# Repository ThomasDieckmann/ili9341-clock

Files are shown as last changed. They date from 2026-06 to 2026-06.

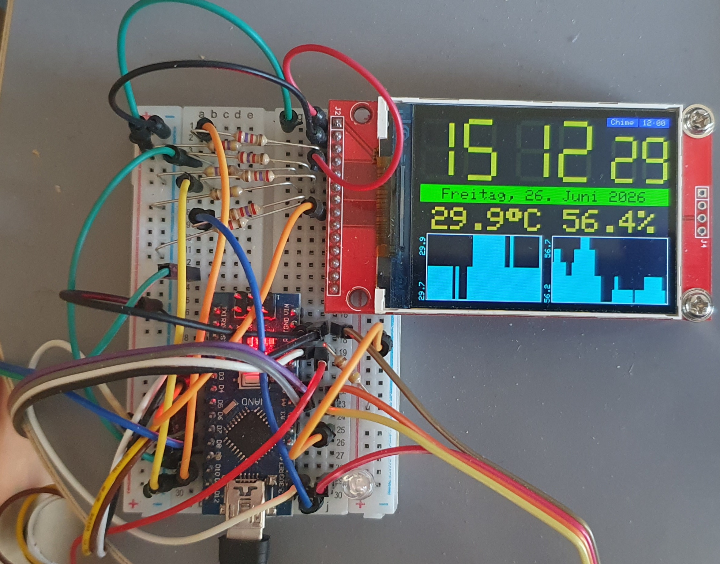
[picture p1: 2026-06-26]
pictures/20260626_144947.jpg

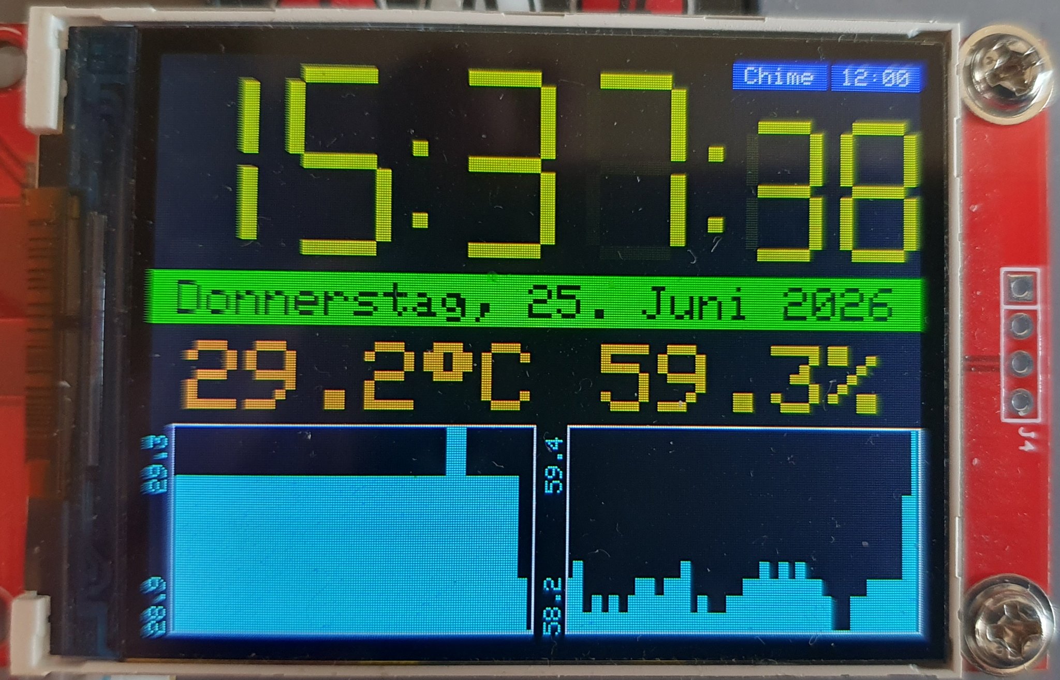
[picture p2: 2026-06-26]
pictures/ili9341-clock.jpeg

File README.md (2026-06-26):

# Uhr mit ILI9341 display

Das war eigentlich eine schnelle Bastelei, die auch zugegebenermaßen noch nicht ganz fertig ist.
So sieht der Code allerdings auch aus. Da könnten irgendwann noch einmal ein paar Kommentare hinein.

Hinweise:
- Viele dieser LCD-Displays kommen als 3,3V-Version ohne Pegelwandler auf den Markt. Daher habe ich
  im Schaltplan die Spannungsteiler eingesetzt. Sollten Pegelwandler verbaut sein, kann der Spannungsteiler
  entfallen und das Display direkt angeschlossen werden.
- Dass alle Segmente gezeichnet werden, ist gewollt. Die inaktiven Segmente werden in einer dunkleren
  Farbe dargestellt, damit der Eindruck eines 7-Segment LED-Displays entsteht. Wen's stört, der kann
  das im Code gerne auf schwarz stellen.

TODO:
- Integration LDR im Code => Steuern LED Hintergrundbeleuchtung
- Alarmfunktion
- Chime-Funktion
- präziseres RTC-Modul finden

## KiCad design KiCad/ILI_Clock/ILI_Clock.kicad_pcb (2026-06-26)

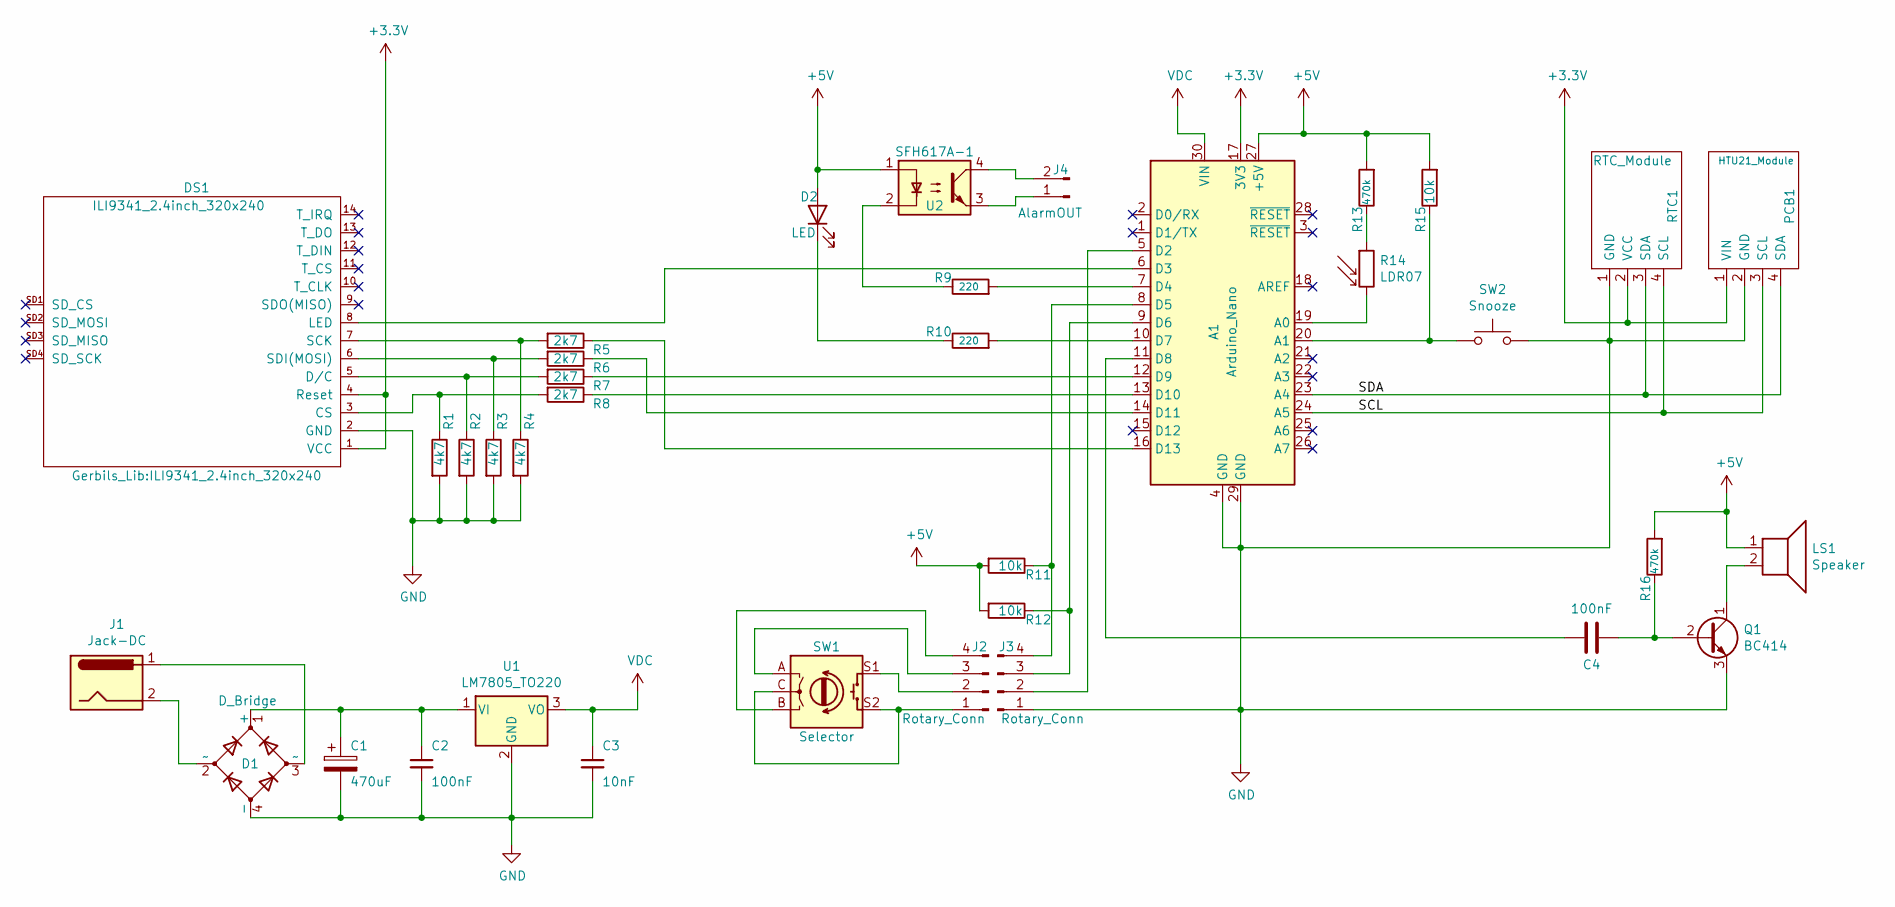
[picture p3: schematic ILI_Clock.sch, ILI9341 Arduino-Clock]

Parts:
A1: Arduino_Nano
C1: 470uF; CP_Radial_D8.0mm_P5.00mm
C2: 100nF; C_Axial_L3.8mm_D2.6mm_P10.00mm_Horizontal
C3: 10nF; C_Axial_L3.8mm_D2.6mm_P10.00mm_Horizontal
C4: 100nF; C_Axial_L5.1mm_D3.1mm_P10.00mm_Horizontal
D1: D_Bridge; Diode_Bridge_Round_D9.8mm
D2: LED; PinHeader_1x02_P2.54mm_Vertical
DS1: ILI9341_2.4inch_320x240
J1: Jack-DC; BarrelJack_CUI_PJ-063AH_Horizontal_CircularHoles
J2, J3: Rotary_Conn; PinHeader_1x04_P2.54mm_Vertical
J4: AlarmOUT; PinHeader_1x02_P2.54mm_Vertical
LS1: Speaker; Buzzer_TDK_PS1240P02BT_D12.2mm_H6.5mm
PCB1: HTU21_Module; HTU21
Q1: BC414; TO-92_Inline
R1, R2, R3, R4: 4k7; R_Axial_DIN0411_L9.9mm_D3.6mm_P12.70mm_Horizontal
R5, R6, R7, R8: 2k7; R_Axial_DIN0411_L9.9mm_D3.6mm_P12.70mm_Horizontal
R9, R10: 220; R_Axial_DIN0411_L9.9mm_D3.6mm_P12.70mm_Horizontal
R11, R12, R15: 10k; R_Axial_DIN0411_L9.9mm_D3.6mm_P12.70mm_Horizontal
R13, R16: 470k; R_Axial_DIN0411_L9.9mm_D3.6mm_P12.70mm_Horizontal
R14: LDR07; R_LDR_5.1x4.3mm_P3.4mm_Vertical
RTC1: RTC_Module; PinHeader_1x04_P2.54mm_Vertical
SW1: Selector; RotaryEncoder_Alps_EC11E-Switch_Vertical_H20mm
SW2: Snooze; PinHeader_1x02_P2.54mm_Vertical
U1: LM7805_TO220; TO-220-3_Horizontal_TabDown
U2: SFH617A-1; DIP-4_W7.62mm

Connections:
+3V3: A1.17 (3V3), DS1.1 (VCC), DS1.4 (Reset), PCB1.1 (VIN), RTC1.2 (VCC)
+5V: A1.27 (+5V), D2.2 (A), LS1.1, R11.2, R12.2, R13.2, R15.2, R16.2, U2.1
/SCL: A1.24 (A5), PCB1.3 (SCL), RTC1.4 (SCL)
/SDA: A1.23 (A4), PCB1.4 (SDA), RTC1.3 (SDA)
GND: A1.4 (GND), A1.29 (GND), C1.2, C2.2, C3.2, D1.4 (-), DS1.2 (GND), J3.1, PCB1.2 (GND), Q1.3 (E), R1.2, R2.2, R3.2, R4.2, RTC1.1 (GND), SW2.2, U1.2 (GND)
unnamed: A1.5 (D2), J3.2
unnamed: A1.6 (D3), DS1.8 (LED)
unnamed: A1.7 (D4), R9.2
unnamed: A1.8 (D5), J3.4, R11.1
unnamed: A1.9 (D6), J3.3, R12.1
unnamed: A1.10 (D7), R10.2
unnamed: A1.11 (D8), C4.2
unnamed: A1.12 (D9), R7.1
unnamed: A1.13 (D10), R8.1
unnamed: A1.14 (D11), R6.1
unnamed: A1.16 (D13), R5.1
unnamed: A1.19 (A0), R14.2
unnamed: A1.20 (A1), R15.1, SW2.1
unnamed: C1.1, C2.1, D1.1 (+), U1.1 (VI)
unnamed: C4.1, Q1.2 (B), R16.1
unnamed: D1.2 (~~), J1.2
unnamed: D1.3 (~~), J1.1
unnamed: D2.1 (K), R10.1
unnamed: DS1.3 (CS), R1.1, R8.2
unnamed: DS1.5 (D/C), R2.1, R7.2
unnamed: DS1.6 (SDI(MOSI)), R3.1, R6.2
unnamed: DS1.7 (SCK), R4.1, R5.2
unnamed: J2.1, SW1.C, SW1.S2
unnamed: J2.2, SW1.S1
unnamed: J2.3, SW1.A
unnamed: J2.4, SW1.B
unnamed: J4.1, U2.3
unnamed: J4.2, U2.4
unnamed: LS1.2, Q1.1 (C)
unnamed: R9.1, U2.2
unnamed: R13.1, R14.1
VDC: A1.30 (VIN), C3.1, U1.3 (VO)

Board: 2 copper layers, 36 parts (0 on the bottom side), 37 nets, no tracks yet.

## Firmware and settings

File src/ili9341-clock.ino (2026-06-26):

// #define DEBUG           // general debugging
// #define DISPLAY_ALIGN   // debug display alignment
// #define SET_TIME        // set time for first run
// #define DEBUG_STATS     // debugging for statistics
// #define DEBUG_DATE      // debugging date display

#include "SPI.h"
#include "Adafruit_GFX.h"
#include "Adafruit_ILI9341.h"

#include <Wire.h>
#include "RTClib.h"
#include "SparkFunHTU21D.h"

/*  define the 7 segments: https://en.wikipedia.org/wiki/Seven-segment_display
         _____
      _ <__A__> _ 
     | |       | |
     | |       | |
     |F|       |B|
     | |       | |
     |_| _____ |_|
      _ <__G__> _ 
     | |       | |
     | |       | |
     |E|       |C|
     | |       | |
     |_| _____ |_|
        <__D__>         */

/* Color definitions
#define ILI9341_BLACK 0x0000       ///<   0,   0,   0
#define ILI9341_NAVY 0x000F        ///<   0,   0, 123
#define ILI9341_DARKGREEN 0x03E0   ///<   0, 125,   0
#define ILI9341_DARKCYAN 0x03EF    ///<   0, 125, 123
#define ILI9341_MAROON 0x7800      ///< 123,   0,   0
#define ILI9341_PURPLE 0x780F      ///< 123,   0, 123
#define ILI9341_OLIVE 0x7BE0       ///< 123, 125,   0
#define ILI9341_LIGHTGREY 0xC618   ///< 198, 195, 198
#define ILI9341_DARKGREY 0x7BEF    ///< 123, 125, 123
#define ILI9341_BLUE 0x001F        ///<   0,   0, 255
#define ILI9341_GREEN 0x07E0       ///<   0, 255,   0
#define ILI9341_CYAN 0x07FF        ///<   0, 255, 255
#define ILI9341_RED 0xF800         ///< 255,   0,   0
#define ILI9341_MAGENTA 0xF81F     ///< 255,   0, 255
#define ILI9341_YELLOW 0xFFE0      ///< 255, 255,   0
#define ILI9341_WHITE 0xFFFF       ///< 255, 255, 255
#define ILI9341_ORANGE 0xFD20      ///< 255, 165,   0
#define ILI9341_GREENYELLOW 0xAFE5 ///< 173, 255,  41
#define ILI9341_PINK 0xFC18        ///< 255, 130, 198   */

// For the Adafruit shield, these are the default.
#define TFT_DC     9
#define TFT_CS    10
#define TFT_MISO  12
#define TFT_MOSI  11
#define TFT_CLK   13
#define TFT_RST   A7

#define BAUDRATE 115200
#define LEDPIN 3

#define CLK_PIN           6    // Rotary Encoder Pins  // Definition der Pins. CLK an D6, DT an D5. 
#define DT_PIN            5    // Rotary Encoder Pins
#define SW_PIN            2    // Switch is connected to D2 Verbunden. CAVE : use an interrupt pin!
#define MAXMENU           8    // Anzahl der Setup-Menü-Einträge
#define MAXVALUES        40    // array sizes for temp and humid stats
//#define MAXVALUES        3    // array sizes for temp and humid stats
#define DEFAULT_BRIGHT   50    // default brightness

int   date_text_length      = 0,
      encoderVal            = 0,
      change                = 0,
      MenuSelection         = MAXMENU,  // default Menü-Eintrag
      date_year             = 2021,
      segment_height        = 20, // 7-Segment-Display values
      segment_width         = 5,
      segment_color         = ILI9341_BLUE,
      humd_array[MAXVALUES],
      temp_array[MAXVALUES],
      array_pointer         = -1,
      maximum_temp          = -32000,
      minimum_temp          = 32000,
      maximum_humd          = 0,
      minimum_humd          = 2000;

bool  SelectCelsius         = true,
      AlarmOnOff            = true,
      HourChime             = true,
      SW_pressed            = false,
      adjust_alarm_hour     = false,
      adjust_alarm_minute   = false,
      adjust_time_hour     = false,
      adjust_time_minute   = false,
      adjust_date_day       = false,
      adjust_date_month     = false,
      adjust_date_year      = false,
      time_has_changed      = false,
      date_has_changed      = false,
      alarm_has_changed     = true,
      chime_has_changed     = true,
      stats_have_changed    = true,
      year_can_be_added     = false,   // append 4-digit year to output string
      locking_insert_stats  = false;   // can lock this, to prevent inserting multiple same values in one second

byte  stunde_digit1_alt     = 11,  // init-Werte egal, Hauptsache Unterscheidlich alt ./. neu
      stunde_digit2_alt     = 11,
      stunde_digit1_neu     = 1,
      stunde_digit2_neu     = 1,
      minute_digit1_alt     = 11,
      minute_digit2_alt     = 11,
      minute_digit1_neu     = 1,
      minute_digit2_neu     = 1,
      sekunde_digit1_alt    = 11,
      sekunde_digit2_alt    = 11,
      sekunde_digit1_neu    = 1,
      sekunde_digit2_neu    = 1,
      alarm_hour            = 12,
      alarm_minute          = 0,
      time_hour             = 12,
      time_minute           = 0,
      date_day              = 1,
      date_day_old          = 32,  // first run, we'll draw a date
      date_month            = 1,
      display_brightness    = DEFAULT_BRIGHT;

float humd,
      temp,
      humd_alt              = 0,
      temp_alt              = 9999;

// Use hardware SPI (on Uno, #13, #12, #11) and the above for CS/DC
Adafruit_ILI9341 tft = Adafruit_ILI9341(TFT_CS, TFT_DC);

// If using the breakout, change pins as desired
//Adafruit_ILI9341 tft = Adafruit_ILI9341(TFT_CS, TFT_DC, TFT_MOSI, TFT_CLK, TFT_RST, TFT_MISO);

// Date and time functions using a DS1307 RTC connected via I2C and Wire lib
RTC_DS1307 rtc;
// char daysOfTheWeek[7][12] = {"Sunday",  "Monday", "Tuesday",  "Wednesday", "Thursday",   "Friday",  "Saturday"};
   char daysOfTheWeek[7][12] = {"Sonntag", "Montag", "Dienstag", "Mittwoch",  "Donnerstag", "Freitag", "Samstag"};
// char daysOfTheWeek[7][12] = {"So", "Mo", "Di", "Mi", "Do", "Fr", "Sa"};
// char monthsOfTheYear[12][11] = {"January", "February", "March", "April",  "May", "June", "July", "August", "September", "October", "November", "December"};
// char monthsOfTheYear[12][11] = {"Januar",  "Februar",  "März",  "April",  "Mai", "Juni", "Juli", "August", "September", "Oktober", "November", "Dezember"};
// char monthsOfTheYear[12][11] = {"Januar",  "Februar",  77 0x84 114 122,  "April",  "Mai", "Juni", "Juli", "August", "September", "Oktober", "November", "Dezember"};
//   char monthsOfTheYear[12][11] = {"Januar",  "Februar", 0x4D0x840x720x7A ,  "April",  "Mai", "Juni", "Juli", "August", "September", "Oktober", "November", "Dezember"};
   char monthsOfTheYear[12][11] = {"Januar",  "Februar", "\x4d\x84\x72\x7a" ,  "April",  "Mai", "Juni", "Juli", "August", "September", "Oktober", "November", "Dezember"};


//Create an instance of the object
HTU21D myHumidity;



void setup() {
              
   Serial.begin(BAUDRATE);
   Serial.println(F("ILI9341 Clock")); 

   //
   //
   // redo the map function, not enough precision!
   //
   //
   /*for (int i = 0; i < 145; i++ ) {
      Serial.print(i);  // we're having a higher display pixel window space than values in array!
      Serial.print(' ');
      Serial.print(remap(i, 0, 145, 0, 3));  // we're having a higher display pixel window space than values in array!
      Serial.println(' ');
   }*/
//   while (1);
   pinMode(A2,OUTPUT);
   digitalWrite(A2,HIGH);

   // init array for stats
   #ifdef DEBUG_STATS
      Serial.print("init array: ");
   #endif
   for (int i = 0; i < MAXVALUES; i++)
   {
      humd_array[i] = 0;
      temp_array[i] = 0;
      #ifdef DEBUG_STATS
         Serial.print(i);
         Serial.print(' ');
      #endif
   }
   #ifdef DEBUG_STATS
      Serial.println(' ');
   #endif

   pinMode(LEDPIN, OUTPUT);
   analogWrite(LEDPIN, display_brightness);
  
   tft.begin();
   if (! rtc.begin()) {
      Serial.println(F("Couldn't find 1307-RTC"));
      while (1);
   } else {
      Serial.println(F("RTC found"));
   }

   tone(8,680,80);
   delay(130);
   tone(8,440,80);
   delay(130);
   tone(8,560,120);
   delay(130);
   noTone(8);
   yield();
   analogWrite(LEDPIN,display_brightness);
    
   myHumidity.begin();

   // init rotary encoder
   pinMode(SW_PIN, INPUT_PULLUP);   // Hier wird der Interrupt installiert.
   //attachInterrupt(digitalPinToInterrupt(SW_PIN), SW_Interrupt, LOW);
   attachInterrupt(digitalPinToInterrupt(SW_PIN), SW_Interrupt, LOW);

   pinMode(CLK_PIN, INPUT_PULLUP);
   pinMode(DT_PIN, INPUT_PULLUP);

   if (! rtc.isrunning()) {
      Serial.println("RTC is NOT running!");
      // following line sets the RTC to the date & time this sketch was compiled
      // rtc.adjust(DateTime(F(__DATE__), F(__TIME__)));
      // This line sets the RTC with an explicit date & time, for example to set
      // August 8, 2021 at 0:35 you would call:
      #ifdef SET_TIME
          rtc.adjust(DateTime(2021, 8, 25, 17, 11, 0));
      #endif
      MenuSelection = 5;
      SW_pressed = true;
      CallSetupMenu();
   }

  
   DateTime now = rtc.now();
   #ifdef DEBUG
      Serial.print(now.day(), DEC);
      Serial.print(". ");
      Serial.print(monthsOfTheYear[now.month()]);
      Serial.print(' ');
      Serial.print(now.year(), DEC);
      Serial.print(" (");
      Serial.print(daysOfTheWeek[now.dayOfTheWeek()]);
      Serial.print(") ");
      Serial.print(now.hour(), DEC);
      Serial.print(':');
      Serial.print(now.minute(), DEC);
      Serial.print(':');
      Serial.print(now.second(), DEC);
      Serial.println();
      // read diagnostics (optional but can help debug problems)
      uint8_t x = tft.readcommand8(ILI9341_RDMODE);
      Serial.print("Display Power Mode: 0x"); Serial.println(x, HEX);
      x = tft.readcommand8(ILI9341_RDMADCTL);
      Serial.print("MADCTL Mode: 0x"); Serial.println(x, HEX);
      x = tft.readcommand8(ILI9341_RDPIXFMT);
      Serial.print("Pixel Format: 0x"); Serial.println(x, HEX);
      x = tft.readcommand8(ILI9341_RDIMGFMT);
      Serial.print("Image Format: 0x"); Serial.println(x, HEX);
      x = tft.readcommand8(ILI9341_RDSELFDIAG);
      Serial.print("Self Diagnostic: 0x"); Serial.println(x, HEX); 
   #endif

   tft.setRotation(3);
   tft.fillScreen(ILI9341_BLACK);

   size_7segment (15);
   color_7segment(0xFFE0);
   display_7segment ('P',  20, 65);
   display_7segment ('U',  80, 65);
   display_7segment ('L', 140, 65);
   display_7segment ('S', 200, 65);
   display_7segment ('E', 260, 65);
   delay(2000);
  
   size_7segment (6);

   tft.setRotation(3);

   // CallSetupMenu();

   tft.fillScreen(ILI9341_BLACK);
   pulse_logo();
   delay(6000);
   tft.fillScreen(ILI9341_BLACK);

   tft.setTextSize(5);
   SW_pressed = false;
 
   tft.fillScreen(ILI9341_BLACK);


   /* Test für Schaltjahresberechnung
   for (int i = 2020; i < 2800; i++) {
       Serial.print (i); Serial.print (": ");
       Serial.println (28 + int((4-(i%4))/4) - int((100-(i%100))/100) + int((400-(i%400))/400) );
   }*/ 
}


void loop() {

   showClock();
   delay (30);
 
   float humd = myHumidity.readHumidity();
   float temp = myHumidity.readTemperature();

   #ifdef DEBUG
     Serial.print(F(" Temperature: "));
     Serial.print(temp, 3);
     Serial.print("C");
     Serial.print(F(" Humidity: "));
     Serial.print(humd, 3);
     Serial.print('%');
     Serial.println();
   #endif
  
   if (SW_pressed == true) {
      SW_pressed = false;
      CallSetupMenu();
      tft.fillScreen(ILI9341_BLACK);
   }
}


void showClock() {
  
   tft.setRotation(3);

   #ifdef DISPLAY_ALIGN
      tft.fillRect(0, 0, 1, 240, ILI9341_WHITE);
      tft.fillRect(319, 0, 1, 240, ILI9341_WHITE);
      tft.drawLine(319,0,319,239,ILI9341_WHITE);
   #endif

   segment_color = ILI9341_YELLOW;

   // Uhrzeit übertragen
   DateTime now = rtc.now();
   stunde_digit1_neu  = now.hour() / 10;
   stunde_digit2_neu  = now.hour() % 10;
   minute_digit1_neu  = now.minute() / 10;
   minute_digit2_neu  = now.minute() % 10;
   sekunde_digit1_neu = now.second() / 10;
   sekunde_digit2_neu = now.second() % 10;

   date_day = now.day();
   date_month = now.month();
   date_year = now.year();
  
   size_7segment(14); 
   if (stunde_digit1_neu != stunde_digit1_alt) {
       stunde_digit1_alt = stunde_digit1_neu;   display_7segment (char(48 + stunde_digit1_neu), 0, 6);
   }
   if (stunde_digit2_neu != stunde_digit2_alt) {
       stunde_digit2_alt = stunde_digit2_neu;   display_7segment (char(48 + stunde_digit2_neu), 55, 6);
   }

   if (sekunde_digit2_neu != sekunde_digit2_alt) {
      if (sekunde_digit2_neu%2 == 1) {
         display_dots (false, false, 106, 6);
      } else {
         display_dots (true, true, 106, 6);        
      }
   }
   
   if (minute_digit1_neu != minute_digit1_alt) {
       minute_digit1_alt = minute_digit1_neu;   display_7segment (char(48 + minute_digit1_neu), 123, 6);
   }
   if (minute_digit2_neu != minute_digit2_alt) {
       minute_digit2_alt = minute_digit2_neu;   display_7segment (char(48 + minute_digit2_neu), 178, 6);
   }

   if (sekunde_digit2_neu != sekunde_digit2_alt) {
      if (sekunde_digit2_neu%2 == 1) {
         display_dots (false, false, 230, 6);
      } else {
         display_dots (true, true, 230, 6);        
      }
   }
   // seconds digits may be smaller
   size_7segment(10); 
   if (sekunde_digit1_neu != sekunde_digit1_alt) {
       sekunde_digit1_alt = sekunde_digit1_neu; display_7segment (char(48 + sekunde_digit1_neu), 246, 25);
   }
   if (sekunde_digit2_neu != sekunde_digit2_alt) {
       sekunde_digit2_alt = sekunde_digit2_neu; display_7segment (char(48 + sekunde_digit2_neu), 286, 25);
   }

   // Output new date
   if (date_day_old != now.day())
   {
      year_can_be_added = false;
      date_day_old = now.day();
      tft.setTextColor(ILI9341_BLACK);
      tft.setTextSize(2);
      // 5 Chars (,. ) + date text + month text + day text
      date_text_length = 4 + 2 + strlen(daysOfTheWeek[now.dayOfTheWeek()]) + strlen(monthsOfTheYear[now.month()-1]);
      if (now.day() < 10) date_text_length -= 1;
      if (date_text_length < 22) {
         date_text_length+=5;  // if string is not too long, we can add the year
         year_can_be_added = true;
      }
      tft.fillRect (0, 91, 320, 22, ILI9341_GREEN);
      tft.setCursor((320 - date_text_length * 12) / 2, 95);
      tft.print(daysOfTheWeek[now.dayOfTheWeek()]);
      tft.print(", ");
      tft.print(now.day());
      tft.print(". ");
      tft.print(monthsOfTheYear[now.month()-1]);
      // add year, if length short enough
      if (year_can_be_added) {
         tft.print(" ");
         tft.print(now.year());
      }
      #ifdef DEBUG_DATE
         Serial.print("length of complete date string: ");
         Serial.print(date_text_length);
         Serial.print("\nlength of day of week ");
         Serial.print(daysOfTheWeek[now.dayOfTheWeek()]);
         Serial.print(": ");
         Serial.print(strlen(daysOfTheWeek[now.dayOfTheWeek()]));
         Serial.print("\nlength of month string ");
         Serial.print(monthsOfTheYear[now.month()-1]);
         Serial.print(": ");
         Serial.println(strlen(monthsOfTheYear[now.month()-1]));
      #endif
   }
   //just for debugging alignment => center
   //for (int i=12;i<315;i+=12) tft.drawLine(i, 100, i, 170, ILI9341_WHITE);
   //tft.fillRect (0, 115, 320, 20, ILI9341_BLACK);
   //tft.setCursor(1, 115);
   //tft.print(date_text_length);


   float humd = myHumidity.readHumidity();
   float temp = myHumidity.readTemperature();
 
   if (calculate_divergence(temp, temp_alt) > 0) {
      temp_alt = temp;
      tft.setTextColor(ILI9341_ORANGE);
      tft.setTextSize(4);
      tft.fillRect (15, 120, 145, 30, ILI9341_BLACK);
      tft.setCursor(15, 120);
      if (SelectCelsius) {
         tft.print(temp, 1);
         tft.print(char(247));
         tft.print('C');
      } else {
         tft.print(convert_c2f(temp));
         tft.print(char(247));
         tft.print('F');
      }
   }
   if (calculate_divergence(humd, humd_alt) > 0) {
      humd_alt = humd;
      tft.setTextColor(ILI9341_ORANGE);
      tft.setTextSize(4);
      tft.fillRect (185, 120, 145, 30, ILI9341_BLACK);
      tft.setCursor(185, 120);
      tft.print(humd, 1);
      tft.print('%');
   }


   // draw chime and alarm indicators
   tft.setTextSize(1);
   tft.setTextColor(ILI9341_WHITE);
      
   if (alarm_has_changed) {
      alarm_has_changed = false;
      if (AlarmOnOff) {
         tft.fillRect(282,0,40,11,ILI9341_BLUE);
         tft.setCursor(286, 2);
         if (alarm_hour<10) tft.print('0');
         tft.print(alarm_hour);
         tft.print(':');
         if (alarm_minute<10) tft.print('0');
         tft.print(alarm_minute);
      } else {
         tft.fillRect(282,0,40,11,ILI9341_BLACK);     
      }
   }
   
   if (chime_has_changed) {
      chime_has_changed = false;
      if (HourChime) {
         tft.fillRect(240,0,40,11,ILI9341_BLUE);
         tft.setCursor(245, 2);
         tft.print("Chime");    
      } else {
         tft.fillRect(240,0,40,11,ILI9341_BLACK);        
      }
   }

   // draw statistic boxes
   if (stats_have_changed) {
      stats_have_changed = false;
      tft.setTextColor(ILI9341_CYAN);
      tft.setRotation(2);      // paint maximum and minimum values
      if (array_pointer >= 0) {
         tft.fillRect (0, 0, 85, 8, ILI9341_BLACK);
         tft.setCursor(0, 0);
         tft.print(float(minimum_temp/10.0),1);
         tft.setCursor(58, 0);
         tft.print(float(maximum_temp/10.0),1);
         tft.fillRect (0, 162, 85, 8, ILI9341_BLACK);
         tft.setCursor(0, 162);
         tft.print(float(minimum_humd/10.0),1);
         tft.setCursor(58, 162);
         tft.print(float(maximum_humd/10.0),1);              
      }
      tft.setRotation(3);
      tft.drawRect (9,   154, 149, 86, ILI9341_LIGHTGREY); // draw boxes for stats
      tft.drawRect (171, 154, 149, 86, ILI9341_LIGHTGREY);
   }

   //   if (now.minute()%2 == 0 && now.second() == 0) stats_have_changed = true;
   if (now.second() == 0) stats_have_changed = true;  // filling every minute
   if (stats_have_changed && !locking_insert_stats) {
      append_new_array_values(int(temp * 10.0), int(humd * 10.0)); // so we don't need to store in float array, int will be enough
      locking_insert_stats = true;
      #ifdef DEBUG
         tft.fillRect(250,200,40,15,ILI9341_BLACK);
         tft.setCursor(250,200);
         tft.setTextSize(2);
         tft.print(array_pointer);
         for (int i = 0; i < MAXVALUES; i++)
         {
            Serial.print(humd_array[i]);
            Serial.print(' ');
         }
         Serial.println(' ');
         for (int i = 0; i < MAXVALUES; i++)
         {
            Serial.print(temp_array[i]);
            Serial.print(' ');
         }
         Serial.println(' ');
      #endif

      // tft.drawRect( 10, 155, 147, 84, ILI9341_BLUE);  // area for stats
      // tft.drawRect(172, 155, 147, 84, ILI9341_BLUE);  // area for stats
     
      for (int i = 0; i < 146; i++) {
          //
          //
          // redo the map function, not enough precision!
          //
          //
          int array_element = remap(i, 0, 145, 0, min(array_pointer,MAXVALUES -1));  // we're having a higher display pixel window space than values in array!

          int y_temp=map(temp_array[array_element],minimum_temp,maximum_temp,238,154);
          int y_humd=map(humd_array[array_element],minimum_humd,maximum_humd,238,154);
          tft.drawLine(11+i , 155,    11+i,  y_temp, ILI9341_BLACK);
          tft.drawLine(11+i , y_temp, 11+i,  155+84, ILI9341_CYAN);
          tft.drawLine(172+i, 155,    172+i, y_humd, ILI9341_BLACK);
          tft.drawLine(172+i, y_humd, 172+i, 155+84, ILI9341_CYAN);
             
          #ifdef DEBUG_STATS
             if (y_humd < 154 || y_temp < 154) { // finde den Fehler
                Serial.print("Array Pointer: "); Serial.println(array_pointer);
                Serial.print("min_temp: "); Serial.print(minimum_temp); Serial.print("   max_temp: "); Serial.println(maximum_temp);
                Serial.print("min_humd: "); Serial.print(minimum_humd); Serial.print("   max_humd: "); Serial.println(maximum_humd);
                Serial.print("y_temp: ");Serial.print(y_temp); Serial.print("  y_humd: "); Serial.println(y_humd);
                for (int i = 0; i < 146; i++) {
                    int array_element = remap(i, 0, 145, 0, min(array_pointer,MAXVALUES -1));  // we're having a higher display pixel window space than values in array!
                    Serial.print(array_element); Serial.print(' ');
                }
                Serial.println(' '); Serial.print("humd: ");
                for (int i = 0; i < 146; i++) {
                    int array_element = remap(i, 0, 145, 0, min(array_pointer,MAXVALUES -1));  // we're having a higher display pixel window space than values in array!
                    //int y_humd = map(humd_array[array_element],minimum_humd,maximum_humd,0,83) + 155;
                    Serial.print(humd_array[array_element]); Serial.print(' ');
                }
                Serial.println(' '); Serial.print("temp: ");
                for (int i = 0; i < 146; i++) {
                    int array_element = remap(i, 0, 145, 0, min(array_pointer,MAXVALUES -1));  // we're having a higher display pixel window space than values in array!
                    //int y_humd = map(humd_array[array_element],minimum_humd,maximum_humd,0,83) + 155;
                    Serial.print(temp_array[array_element]); Serial.print(' ');
                }
                Serial.println(' ');
                while (1) { analogWrite(LEDPIN,0); delay(50); analogWrite(LEDPIN,60); delay(150); }
             }
          #endif
      }
   }
   if (now.second() > 0) locking_insert_stats = false;  // unlock   
}
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
